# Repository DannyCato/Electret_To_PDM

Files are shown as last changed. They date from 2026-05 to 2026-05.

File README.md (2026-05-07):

# Electret To PDM

This is a KiCad project that uses a FAN3852 to convert analog electret microphone data to PDM data. It is mounted on a 2-layer PCB with all the parts on the top layer

Additionally, it has grounded mounting pads and a power good LED to see if the connection is working.

## Usage

To be used where there is no better option to turn analog microphone signals into a digital signal. In my case, a Sigma-Delta ADC was used to convert the PDM data into PCM data so that it could more easily be converted into a WAV File for our data collection.

A 1-4 MHz Clock signal should be provided for the FAN Chip to produce PDM data. 

## Connectors
MOLEX SL 70555 series connectors (4 pin for PDM side and 2 pin for Electret side) are used for this board, but switching them out for something else is not difficult

## Schematic

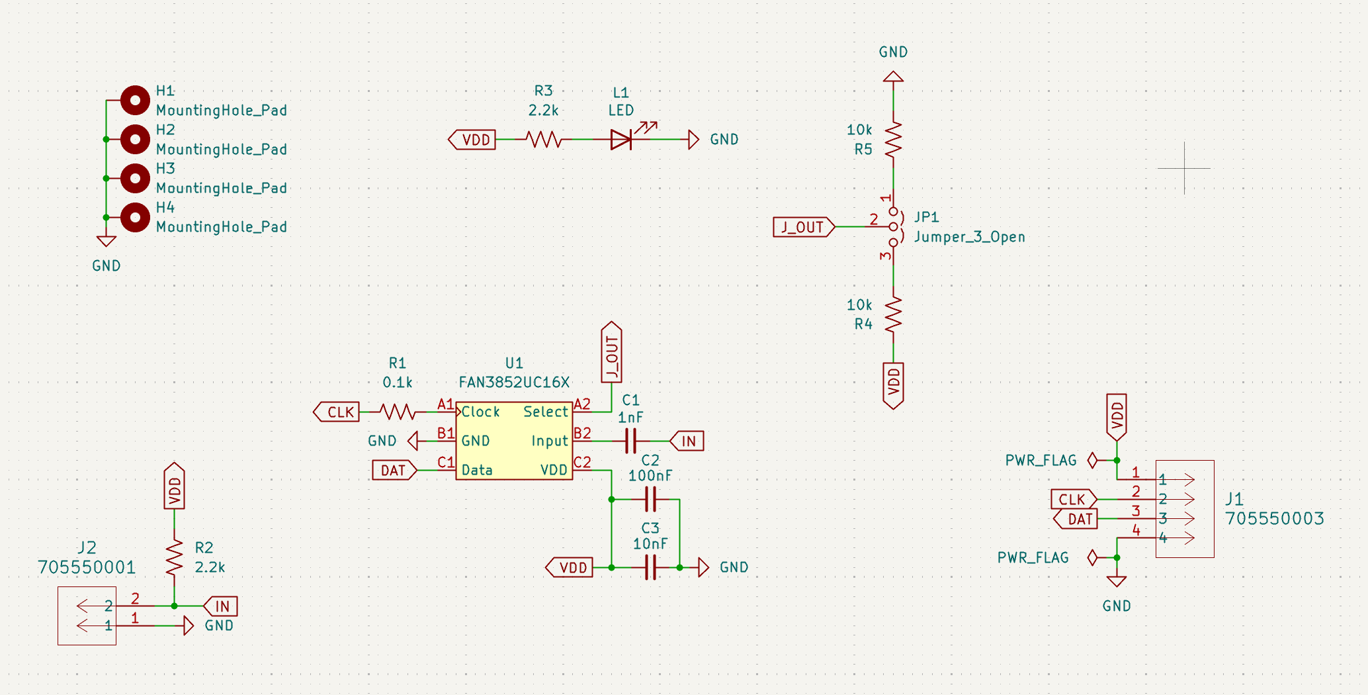
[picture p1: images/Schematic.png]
Schematic


## Layout

The back layer is almost entire a Ground Plane aside for the few times where wires need to cross over others.

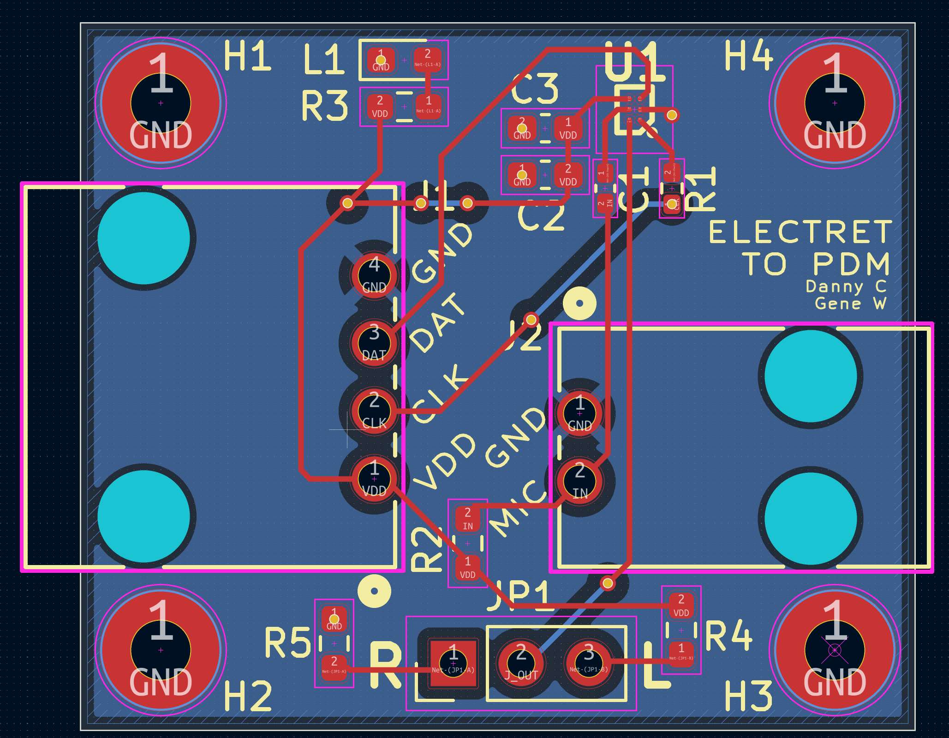
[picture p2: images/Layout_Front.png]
Layout Front


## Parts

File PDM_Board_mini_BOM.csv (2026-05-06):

Reference | Qty | Value | DNP | Exclude from BOM | Exclude from Board | Footprint | Datasheet
C1 | 1 | 1nF |  |  |  | Capacitor_SMD:C_0402_1005Metric_Pad0.74x0.62mm_HandSolder
C2 | 1 | 100nF |  |  |  | Capacitor_SMD:C_0603_1608Metric_Pad1.08x0.95mm_HandSolder
C3 | 1 | 10nF |  |  |  | Capacitor_SMD:C_0603_1608Metric_Pad1.08x0.95mm_HandSolder
J1 | 1 | 705550003 |  |  |  | pdm_board_mini_library:MOLEX_SL_7055503_4PRA | https://www.molex.com/en-us/products/part-detail-pdf/705550003?display=pdf
J2 | 1 | 705550001 |  |  |  | pdm_board_mini_library:MOLEX_SL_7055501_2PRA | https://www.molex.com/en-us/products/part-detail-pdf/705550001?display=pdf
L1 | 1 | LED |  |  |  | LED_SMD:LED_0603_1608Metric_Pad1.05x0.95mm_HandSolder
R1 | 1 | 0.1k |  |  |  | Resistor_SMD:R_0402_1005Metric_Pad0.72x0.64mm_HandSolder
R2,R3 | 2 | 2.2k |  |  |  | Resistor_SMD:R_0603_1608Metric_Pad0.98x0.95mm_HandSolder
R4,R5 | 2 | 10k |  |  |  | Resistor_SMD:R_0603_1608Metric_Pad0.98x0.95mm_HandSolder
U1 | 1 | FAN3852UC16X |  |  |  | pdm_board_mini_library:BGA6C40P2X3_84X124X50 | https://www.onsemi.com/download/data-sheet/pdf/fan3852-d.pdf

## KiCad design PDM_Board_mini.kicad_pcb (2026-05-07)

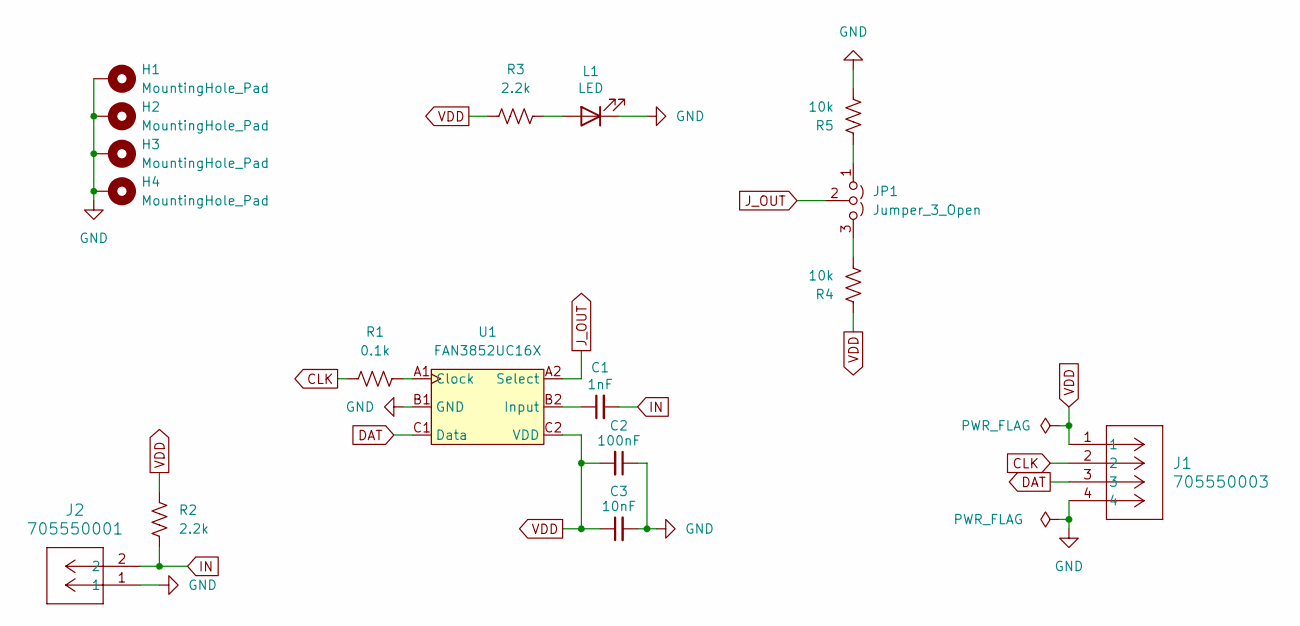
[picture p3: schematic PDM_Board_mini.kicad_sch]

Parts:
C1: 1nF; C_0402_1005Metric_Pad0.74x0.62mm_HandSolder
C2: 100nF; C_0603_1608Metric_Pad1.08x0.95mm_HandSolder
C3: 10nF; C_0603_1608Metric_Pad1.08x0.95mm_HandSolder
H1, H2, H3, H4: MountingHole_Pad; MountingHole_2.2mm_M2_Pad
J1: 705550003; MOLEX_SL_7055503_4PRA
J2: 705550001; MOLEX_SL_7055501_2PRA
JP1: Jumper_3_Open; PinHeader_1x03_P2.54mm_Vertical
L1: LED; LED_0603_1608Metric_Pad1.05x0.95mm_HandSolder
R1: 0.1k; R_0402_1005Metric_Pad0.72x0.64mm_HandSolder
R2, R3: 2.2k; R_0603_1608Metric_Pad0.98x0.95mm_HandSolder
R4, R5: 10k; R_0603_1608Metric_Pad0.98x0.95mm_HandSolder
U1: FAN3852UC16X; BGA6C40P2X3_84X124X50

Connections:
CLK: J1.2, R1.1
DAT: J1.3, U1.C1 (Data)
GND: C2.1, C3.2, H1.1 (1_1), H2.1 (1_1), H3.1 (1_1), H4.1 (1_1), J1.4, J2.1, L1.1 (K), R5.1, U1.B1 (GND)
IN: C1.2, J2.2, R2.2
J_OUT: JP1.2 (C), U1.A2 (Select)
unnamed: JP1.1 (A), R5.2
unnamed: JP1.3 (B), R4.1
unnamed: L1.2 (A), R3.1
unnamed: R1.2, U1.A1 (Clock)
unnamed: C1.1, U1.B2 (Input)
VDD: C2.2, C3.1, J1.1, R2.1, R3.2, R4.2, U1.C2 (VDD)

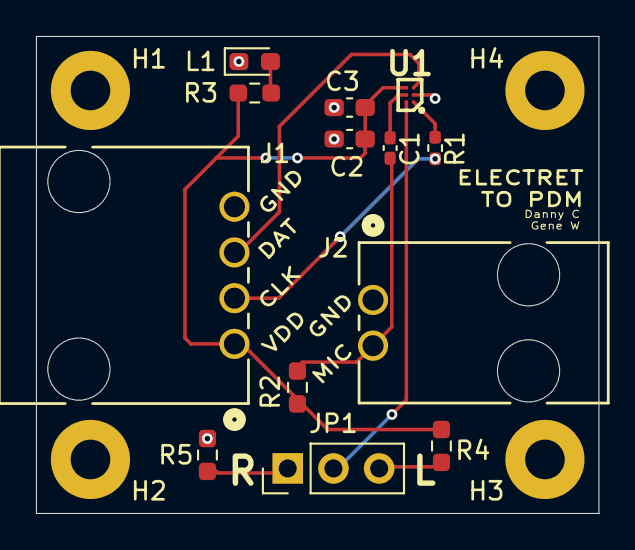
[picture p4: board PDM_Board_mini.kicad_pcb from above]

Board: 2 copper layers, 31.2 x 26.5 mm, 17 parts (0 on the bottom side), 11 nets.

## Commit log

2026-05-06 Initial snapshot: 23 files changed fp-lib-table 4/0/0 Gerber/PDM_Board_mini-B_Cu.gbr 2188/0/0 Gerber/PDM_Board_mini-B_Mask.gbr 2040/0/0 Gerber/PDM_Board_mini-B_Paste.gbr 1995/0/0 Gerber/PDM_Board_min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
    [PDM_Board_mini-B_Cu.gbr, PDM_Board_mini-B_Mask.gbr, PDM_Board_mini-B_Paste.gbr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]
2026-05-06 Project complete
    [PDM_Board_mini-B_Cu.gbr, PDM_Board_mini-B_Mask.gbr, PDM_Board_mini-B_Paste.gbr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]
2026-05-06 Final PCB stuffs
    [PDM_Board_mini-B_Cu.gbr, PDM_Board_mini-B_Mask.gbr, PDM_Board_mini-B_Paste.gbr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]
2026-05-06 Add images of schematic and layout
2026-05-06 Updated PCB to 2 layer with components on only 1 side
    [PDM_Board_mini-B_Cu.gbr, PDM_Board_mini-B_Mask.gbr, PDM_Board_mini-B_Paste.gbr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]
2026-05-06 Intermediate change that should be pushed
    [PDM_Board_mini_BOM.csv]
2026-05-06 Added new gerber and image for 2 side pcb
    [PDM_Board_mini-B_Cu.gbr, PDM_Board_mini-B_Mask.gbr, PDM_Board_mini-B_Paste.gbr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]
2026-05-06 Position file added
    [PDM_Board_mini-all-pos.csv]
2026-05-06 Rename Gerber to Manufacturing Output
    [PDM_Board_mini-B_Cu.gbr, PDM_Board_mini-B_Mask.gbr, PDM_Board_mini-B_Paste.gbr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]
2026-05-07 Redo gerber, drill, and pos with correct offsets
    [PDM_Board_mini-B_Cu.gbl, PDM_Board_mini-B_Cu.gbr, PDM_Board_mini-B_Mask.gbr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]
